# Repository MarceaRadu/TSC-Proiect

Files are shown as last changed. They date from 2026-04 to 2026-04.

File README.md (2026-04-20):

# InkTime - Proiect 

InkTime este un prototip de ceas inteligent construit în jurul platformei SoC nRF52840. Dispozitivul dispune de un display color TFT, conectivitate Bluetooth Low Energy (BLE 5.0), senzor pentru detecția mișcării și utilizează un sistem de alimentare liniar, conceput special pentru a fi eficient în utilizarea cotidiană.

## 2. Tabel Componente (Bill Of Materials)

| Componentă / Rol | Format (Package) | Cod JLCPCB | Fișă Tehnică (Datasheet) |
|---|---|---|---|
| **Microcontroler** (nRF52840-QIAA-R) | aQFN73 (7x7) | [C190794](https://jlcpcb.com/partdetail/Nordic_Semicon-NRF52840_QIAA_R/C190794) | [Datasheet](https://docs.nordicsemi.com/) |
| **Încărcător Baterie** (BQ25120YBGR) | DSBGA-9 | [C1682423](https://jlcpcb.com/partdetail/TexasInstruments-BQ25180YBGR/C3682423) | [Datasheet](https://www.ti.com/lit/ds/symlink/bq25180.pdf) |
| **Fuel Gauge** (MAX17048G+T10) | DFN-8 (2x2) | [C2682616](https://jlcpcb.com/partdetail/AnalogDevices-MAX17048G_T10/C2682616) | [Datasheet](https://www.analog.com/media/en/technical-documentation/data-sheets/MAX17048-MAX17049.pdf) |
| **Regulator Buck-Boost** (RT6160AWSC) | WLCSP-15 | [C7065276](https://jlcpcb.com/partdetail/Richtek_Tech-RT6160AWSC/C7065276) | [Datasheet](https://www.richtek.com/assets/product_file/RT6160A/DS6160A-05.pdf) |
| **Accelerometru** (BMA421) | LGA-12 (2x2) | [C5242966](https://jlcpcb.com/partdetail/Bosch_Sensortec-BMA421/C5242966) | [Datasheet](https://www.bosch-sensortec.com/media/boschsensortec/downloads/datasheets/bst-bma421-ds004.pdf) |
| **Driver Haptic** (DRV2605LDGSR) | VSSOP-10 | [C527464](https://jlcpcb.com/partdetail/TexasInstruments-DRV2605LDGSR/C527464) | [Datasheet](https://www.ti.com/lit/ds/symlink/drv2605l.pdf) |
| **Antenă BLE** (2450AT18B100E) | SMD 3216 | [C5179427](https://jlcpcb.com/partdetail/Johanson_Technology-2450AT18B100E/C5179427) | [Datasheet](https://www.johansontechnology.com/datasheets/2450AT18B100/2450AT18B100.pdf) |
| **Conector FPC** (Molex 503480-2400) | 24-pin 0.5mm FPC | [C2857168](https://jlcpcb.com/partdetail/Molex-5034802400/C2857160) | [Datasheet](https://www.molex.com/en-us/products/part-detail/5034802400) |
| **Butoane** (EVP-AKB31A) | SMD tactil | [C2845028](https://jlcpcb.com/partdetail/Panasonic-EVP_AKE31A/C2845028) | [Datasheet](https://industrial.panasonic.com/cdbs/www-data/pdf/ATV0000/ATV0000CE3.pdf) |
| **Mufă USB-C** (KH-TYPE-C-16P) | 16-pin SMD | [C2765186](https://jlcpcb.com/partdetail/Kinghelm-KH_TYPE_C_16P/C2765186) | [Datasheet](https://datasheet.lcsc.com/lcsc/2012121836_Kinghelm-KH-TYPE-C-16P_C2765186.pdf) |
| **Protecție ESD USB** (USBLC6-2SC6Y) | SOT-23-6 | [C7519](https://jlcpcb.com/partdetail/Stmicroelectronics-USBLC6_2SC6Y/C7519) | [Datasheet](https://www.st.com/resource/en/datasheet/usblc6-2.pdf) |
| **Tranzistor PFET** (Si2301CDS) | SOT-23 | [C10487](https://jlcpcb.com/partdetail/Changjiang_Electronics_Tech_CJ-SI2301CDS/C10487) | [Datasheet](https://www.vishay.com/docs/68749/si2301cds.pdf) |
| **Motor Vibrații** (LCM102733605F) | Fire atașate | [C7528006](https://jlcpcb.com/partdetail/7528806-LCM1027B3605F/C7528806) | [Datasheet](https://datasheet.lcsc.com/lcsc/2310131633_LCM-LCM1027B3605F_C7528806.pdf) |

**Componente Pasive & Periferice:**
* Interfață Programare: Header Tag-Connect 6-pin (TC2030-IDC)
* Cristale Oscilatoare: 32 MHz (2016) și 32.768 kHz (3215)
* Module externe: Display E-Paper / TFT 1.54 inch (FPC 24-pini), Acumulator LiPo 250 mAh
* Inductoare: 0.47uH (2012), 10uH (0402)
* Rezistențe (0201): 2x 10k, 2x 5.1k
* Condensatoare: 4x 12pF (0201), 5x 100nF (0201), 5x 4.7uF (0402), 2x 22uF (0402), 12x 1uF (0402)

## 3. Funcționalitatea Modulelor Hardware

**Unitatea de Procesare și Conectivitatea**
Creierul întregului sistem este cipul nRF52840 (la 64 MHz). Acesta execută logica aplicației și susține comunicarea wireless prin stiva BLE 5.0, permițând legătura cu smartphone-ul pentru sincronizarea timpului și preluarea notificărilor.

**Magistrale și Interfețe**
- **SPI (Doar transmisie):** Alocată exclusiv pentru display-ul TFT. Oferă o lățime de bandă mare, vitală pentru un framerate ridicat și tranziții fluide pe un ecran color.
- **I2C (400 kHz):** Prin intermediul acestei magistrale comunică senzorul inerțial (IMU) LSM6DS3TR-C. Folosirea I2C economisește pini valoroși și ușurează citirea datelor de accelerație.
- **PWM:** Comandă un tranzistor de tip N-MOSFET. Acesta joacă rolul de comutator de putere pentru motorul haptic (shaker-ul BST-BMV080), făcând posibilă generarea unor vibrații cu intensitate variabilă.

**Managementul Energiei (Power System)**
Pentru acest dispozitiv am implementat o arhitectură de alimentare liniară, punând accent pe fiabilitate și simplitate. Modulul BQ24040 primește 5V de la mufa USB-C și încarcă în condiții de siguranță bateria Li-Po de 250mAh (la un curent de 100mA). Mai departe, tensiunea variabilă a bateriei (3.0V - 4.2V) este coborâtă și stabilizată strict la 3.3V cu ajutorul unui regulator LDO (AP2112K). Acest LDO alimentează toată placa și a fost integrat datorită costului scăzut și a lipsei zgomotului electric la curenți mai mici de 600mA.

**Analiza Consumului de Energie**
Ecranele TFT, spre deosebire de cele e-paper, au nevoie de iluminare (backlight) continuă pentru a fi lizibile.
- *Consum în sarcină (Activ):* Aprox. 25 mA (TFT aprins la o luminozitate medie + procesorul activ).
- *Consum în repaus (Stand-by):* Aprox. 0.8 mA (Ecranul este oprit, MCU intră în modul sleep, funcția de BLE advertising este activă, iar IMU-ul așteaptă o mișcare pentru a trezi ceasul).
- *Estimare Autonomie:* Presupunând un scenariu zilnic cu 25 de treziri ale ecranului (a câte 5 secunde) și notificări haptice ocazionale, consumul se ponderează la o medie de 1.1 mA/h. În aceste condiții, acumulatorul de 250mAh asigură o durată de viață teoretică de 8 până la 9 zile de funcționare continuă.

## 4. Maparea Pinilor pentru nRF52840

Pinii au fost distribuiți având ca scop principal optimizarea traseelor de cupru pe placă (routing) și izolarea semnalelor rapide.

| Pin nRF | Periferic | Justificare / Rol Tehnic |
|---|---|---|
| **P0.29** | TFT SCK | Semnal de ceas rapid. Rutat special pe marginea PCB-ului către pamblica ecranului. |
| **P0.31** | TFT MOSI | Pin de date SPI. Tratat în paralel cu SCK pentru a evita degradarea semnalului grafic. |
| **P0.02** | TFT CS | Chip Select (activează display-ul pe magistrală). |
| **P0.26** | TFT DC | Data/Command. Necesar în mod obligatoriu pentru interpretarea comenzilor de către driverul ST7789. |
| **P0.27** | I2C SCL | Semnalul de clock pentru I2C, utilizat exclusiv de IMU. |
| **P0.28** | I2C SDA | Date I2C. Grupate special la distanță de liniile SPI pentru a elimina posibilele interferențe (crosstalk). |
| **P1.11** | Shaker PWM | Portul 1 a fost alocat pentru comenzi mecanice și de forță. Controlează grila tranzistorului de pe motoraș. |
| **P1.04** | Buton 1 (Sus) | GPIO setat ca intrare cu rezistență de pull-up internă. Folosit și pentru a trezi sistemul din hibernare. |
| **P1.05** | Buton 2 (OK) | Intrare digitală. Toți pinii butoanelor sunt adiacenți pentru a face rutarea pe margine extrem de scurtă. |
| **P1.06** | Buton 3 (Jos) | Intrare digitală pentru navigarea interfeței grafice. |
| **VBUS** | 5V USB | Pin hardware nativ al procesorului, capabil să citească prezența curentului de la încărcător. |
| **SWDIO** | Programare | Pin de date folosit la prima "flash-uire" a codului prin SWD / J-Link. |
| **SWDCLK**| Programare | Semnalul de ceas pentru protocolul de depanare SWD. |

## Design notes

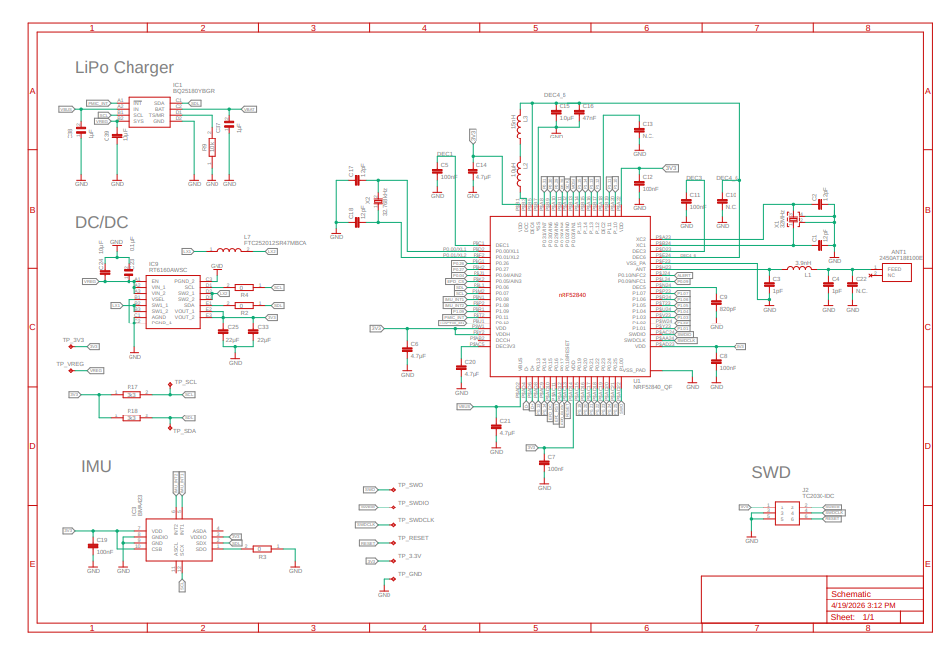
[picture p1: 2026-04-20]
Images/schematic2.png

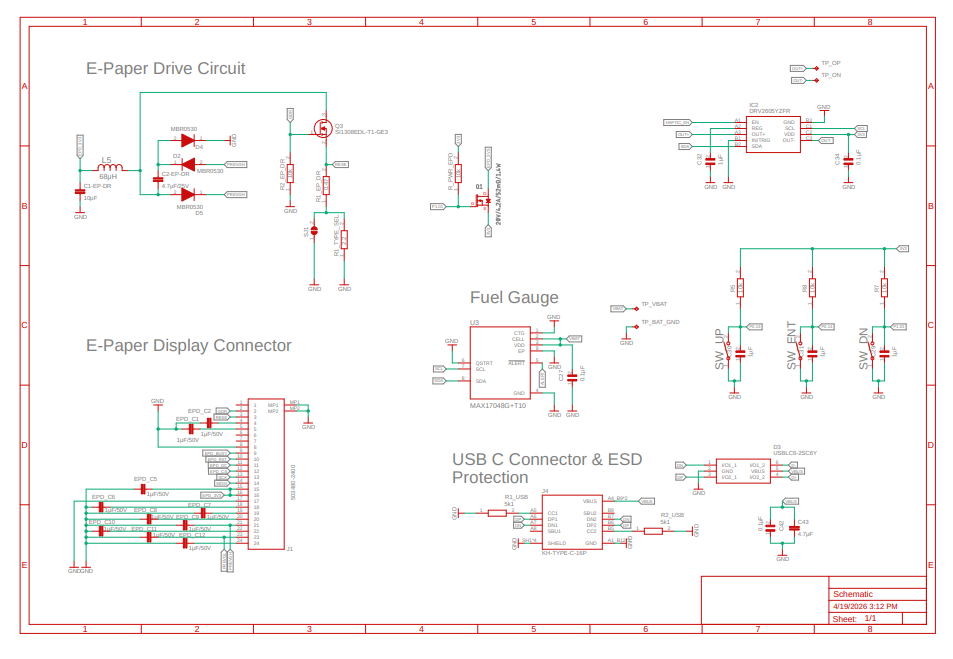
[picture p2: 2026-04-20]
Images/schematic1.png

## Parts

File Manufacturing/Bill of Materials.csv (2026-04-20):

Qty | Value | Device | Package | Parts | Description | ARROW_PART_NUMBER | ARROW_PRICE-STOCK | AVAILABILITY | CHECK_PRICES | COPYRIGHT | DESCRIPTION | DIGI-KEY_PART_NUMBER_1 | DIGI-KEY_PART_NUMBER_2 | DIGI-KEY_PART_NUMBER_3 | HEIGHT | JLCPCB | MANUFACTURER_NAME | MANUFACTURER_PART_NUMBER | MF | MFR_NAME | MOUSER_PART_NUMBER | MOUSER_PRICE-STOCK | MP | PACKAGE | POPULARITY | PRICE | PROD_ID | PURCHASE-URL | SNAPEDA_LINK | SPICEMODEL | SPICEPREFIX | TP_SIGNAL_NAME | VALUE
1 |  | ESP32_C6_LIBRARY_7_JUMPER_SJ | ESP32_C6_LIBRARY_7_JUMPER_SJ | SJ1 | SMD solder JUMPER |  |  |  |  |  |  |  |  |  |  |  |  |  |  |  |  |  |  |  | 3
3 | 0 | ERA-1AEB3401C_CPF0201D7K68C1 | ERA-1AEB3401C_0201 | R2, R3, R4 | 7.68k 0201 Thin Film Surface Mount Fixed Resistor +/-0.5% 0.031W CPF0201D7K68C1
4 | 0.1µF | GRM011R60J152KE01L_2_GRM011R60J152KE01L | GRM011R60J152KE01L_2_CAPC0201X13N | C23, C27, C34, C42 | Check availability |  |  | In Stock | https://www.snapeda.com/parts/GRM011R60J152KE01L/Murata/view-part/?ref=eda |  | SMD Capacitor X5R(EIA) with Capacitance: 1500pF Tol. 10%. Rated Voltage: 6.3Vdc |  |  |  |  |  |  |  | Murata |  |  |  | GRM011R60J152KE01L | 0201 Murata |  | None |  |  | https://www.snapeda.com/parts/GRM011R60J152KE01L/Murata/view-part/?ref=snap
1 | 0.47 | ERA-1AEB3401C_CPF0201D7K68C1 | ERA-1AEB3401C_0201 | R1_EP_DR | 7.68k 0201 Thin Film Surface Mount Fixed Resistor +/-0.5% 0.031W CPF0201D7K68C1
1 | 1.0µF | ESP32_C6_LIBRARY_1_ESP32_WROVER_EAGLE-LTSPICE_CC0402 | ESP32_C6_LIBRARY_1_ESP32_WROVER_EAGLE-LTSPICE_C0402 | C15 | CAPACITOR, European symbol |  |  |  |  |  |  |  |  |  |  |  |  |  |  |  |  |  |  |  |  |  |  |  |  | NONE | C
6 | 100nF | NORDIC_NRF_3_CAPACITOR_0201_L | NORDIC_NRF_3_RESC0201_L | C5, C7, C8, C11, C12, C19 | Generic chip capacitor
6 | 10k | ERA-1AEB3401C_CPF0201D7K68C1 | ERA-1AEB3401C_0201 | R2_EP_DR, R5, R7, R8, R9, R_PWR_EPD | 7.68k 0201 Thin Film Surface Mount Fixed Resistor +/-0.5% 0.031W CPF0201D7K68C1
3 | 10µF | ESP32_C6_LIBRARY_1_ESP32_WROVER_EAGLE-LTSPICE_CC0402 | ESP32_C6_LIBRARY_1_ESP32_WROVER_EAGLE-LTSPICE_C0402 | C1-EP-DR, C24, C39 | CAPACITOR, European symbol |  |  |  |  |  |  |  |  |  |  |  |  |  |  |  |  |  |  |  |  |  |  |  |  | NONE | C
1 | 10µH | NORDIC_NRF_2_INDUCTOR_0201_L | NORDIC_NRF_2_RESC0402_L | L2 | Generic chip inductor
4 | 12pF | NORDIC_NRF_3_CAPACITOR_0201_L | NORDIC_NRF_3_RESC0201_L | C1, C2, C17, C18 | Generic chip capacitor
1 | 15nH | NORDIC_NRF_2_INDUCTOR_0402_L | NORDIC_NRF_2_RESC0402_L | L3 | Generic chip inductor
2 | 1pF | NORDIC_NRF_3_CAPACITOR_0201_L | NORDIC_NRF_3_RESC0201_L | C3, C4 | Generic chip capacitor
6 | 1µF | GRM011R60J152KE01L_2_GRM011R60J152KE01L | GRM011R60J152KE01L_2_CAPC0201X13N | C29, C30, C31, C32, C37, C38 | Check availability |  |  | In Stock | https://www.snapeda.com/parts/GRM011R60J152KE01L/Murata/view-part/?ref=eda |  | SMD Capacitor X5R(EIA) with Capacitance: 1500pF Tol. 10%. Rated Voltage: 6.3Vdc |  |  |  |  |  |  |  | Murata |  |  |  | GRM011R60J152KE01L | 0201 Murata |  | None |  |  | https://www.snapeda.com/parts/GRM011R60J152KE01L/Murata/view-part/?ref=snap
10 | 1µF/50V | PERFECT_0402_CAP_0402 | PERFECT_0402_0402 | EPD_C1, EPD_C2, EPD_C5, EPD_C6, EPD_C7, EPD_C8, EPD_C9, EPD_C10, EPD_C11, EPD_C12 | 0402 (1005 Metric)
1 | 2.2 | ERA-1AEB3401C_CPF0201D7K68C1 | ERA-1AEB3401C_0201 | R1_TYPE_SEL | 7.68k 0201 Thin Film Surface Mount Fixed Resistor +/-0.5% 0.031W CPF0201D7K68C1
3 | 2025-10-22_07-23-44_LIBRARY_EVP-AKE31ASW_EVP-AKE31A_PAN | 2025-10-22_07-23-44_LIBRARY_EVP-AKE31ASW_EVP-AKE31A_PAN | 2025-10-22_07-23-44_LIBRARY_SW_EVP-AKE31A_PAN | SW_DN, SW_ENT, SW_UP |  |  |  |  |  | Copyright (C) 2025 Ultra Librarian. All rights reserved. |  | P123437TR-ND | P123437CT-ND | P123437DKR-ND |  |  | Panasonic | EVP-AKE31A
1 | 20V/4.2A/52mO/1.4W | ESP32_C6_LIBRARY_4_ESP32_WROVER_SPARKFUN-DISCRETESEMI_MOSFET_PCH-DMG2305UX-7 | ESP32_C6_LIBRARY_4_ESP32_C6_LIBRARY_4_ESP32_C6_LIBRARY_4_ESP32_C6_LIBRARY_4_ESP32_WROVER_SPARKFUN-DISCRETESEMI_SOT23-3 | Q1 | P-channel MOSFETs |  |  |  |  |  |  |  |  |  |  |  |  |  |  |  |  |  |  |  |  |  | TRAN-14388 |  |  |  |  |  | 20V/4.2A/52mO/1.4W
2 | 22µF | ESP32_C6_LIBRARY_1_ESP32_WROVER_EAGLE-LTSPICE_CC0402 | ESP32_C6_LIBRARY_1_ESP32_WROVER_EAGLE-LTSPICE_C0402 | C25, C33 | CAPACITOR, European symbol |  |  |  |  |  |  |  |  |  |  |  |  |  |  |  |  |  |  |  |  |  |  |  |  | NONE | C
1 | 2450AT18B100E | 2450AT18B100E_2450AT18B100E | 2450AT18B100E_ANTC3216X140N | ANT1 | Antennas 2.45GHz ANTENNA | 2450AT18B100E | https://www.arrow.com/en/products/2450at18b100e/johanson-dielectrics?utm_currency=USD&region=nac |  |  |  | Antennas 2.45GHz ANTENNA |  |  |  | 1.4mm |  | JOHANSON TECHNOLOGY | 2450AT18B100E |  |  | 609-2450AT18B100E | https://www.mouser.co.uk/ProductDetail/Johanson-Technology/2450AT18B100E?qs=yCnrNFeXz%252Bh5MFsFIXGZGA%3D%3D
1 | 3.9nH | NORDIC_NRF_2_INDUCTOR_0402_L | NORDIC_NRF_2_RESC0402_L | L1 | Generic chip inductor
1 | 32.768kHz | NORDIC_NRF_1_XTAL_32KHZ | NORDIC_NRF_1_XTAL_3215_N | X2
1 | 32MHz | NORDIC_NRF_XTAL_32MHZ | NORDIC_NRF_BT-XTAL_2016_N | X1
2 | 3k3 | ERA-1AEB3401C_CPF0201D7K68C1 | ERA-1AEB3401C_0201 | R17, R18 | 7.68k 0201 Thin Film Surface Mount Fixed Resistor +/-0.5% 0.031W CPF0201D7K68C1
4 | 4.7µF | ESP32_C6_LIBRARY_1_ESP32_WROVER_EAGLE-LTSPICE_CC0402 | ESP32_C6_LIBRARY_1_ESP32_WROVER_EAGLE-LTSPICE_C0402 | C6, C14, C20, C21 | CAPACITOR, European symbol |  |  |  |  |  |  |  |  |  |  |  |  |  |  |  |  |  |  |  |  |  |  |  |  | NONE | C
1 | 4.7µF | PERFECT_0402_CAP_0402 | PERFECT_0402_0402 | C43 | 0402 (1005 Metric)
1 | 4.7µF/25V | ESP32_C6_LIBRARY_1_ESP32_WROVER_EAGLE-LTSPICE_CC0402 | ESP32_C6_LIBRARY_1_ESP32_WROVER_EAGLE-LTSPICE_C0402 | C2-EP-DR | CAPACITOR, European symbol |  |  |  |  |  |  |  |  |  |  |  |  |  |  |  |  |  |  |  |  |  |  |  |  | NONE | C
1 | 47nF | NORDIC_NRF_3_CAPACITOR_0201_L | NORDIC_NRF_3_RESC0201_L | C16 | Generic chip capacitor
1 | 503480-2400 | 503480-2400_503480-2400 | 503480-2400_5034802400 | J1 | FFC & FPC Connectors 0.5mm FPC RA SMT Dual Contact 24Ckt |  |  |  |  |  | FFC & FPC Connectors 0.5mm FPC RA SMT Dual Contact 24Ckt |  |  |  | 1.87mm |  | Molex | 503480-2400 |  |  | 538-503480-2400 | https://www.mouser.co.uk/ProductDetail/Molex/503480-2400?qs=OAhjpuo3Vu7efIoxFh9AOw%3D%3D
2 | 5k1 | ERA-1AEB3401C_CPF0201D7K68C1 | ERA-1AEB3401C_0201 | R1_USB, R2_USB | 7.68k 0201 Thin Film Surface Mount Fixed Resistor +/-0.5% 0.031W CPF0201D7K68C1
1 | 68µH | ESP32_C6_LIBRARY_2_744043680IND_4828-WE-TPC_WRE | ESP32_C6_LIBRARY_2_IND_4828-WE-TPC_WRE | L5 |  |  |  |  |  | Copyright (C) 2024 Ultra Librarian. All rights reserved. |  |  |  |  |  |  |  | 744043680 |  | Wurth Electronics
1 | 820pF | NORDIC_NRF_3_CAPACITOR_0201_L | NORDIC_NRF_3_RESC0201_L | C9 | Generic chip capacitor
1 | BMA423 | BMA423_BMA423 | BMA423_BMA423 | IC3 | Accelerometers Triaxial low-g 12bit Acceleration Sensor | BMA423 | https://www.arrow.com/en/products/bma423/bosch |  |  |  | Accelerometers Triaxial low-g 12bit Acceleration Sensor |  |  |  | 1mm |  | BOSCH | BMA423 |  |  | 262-BMA423 | https://www.mouser.co.uk/ProductDetail/Bosch-Sensortec/BMA423?qs=HXFqYaX1Q2xC%252BSgeGoX3mg%3D%3D
1 | BQ25180YBGR | BQ25180YBGR_BQ25180YBGR | BQ25180YBGR_BGA8C40P2X4_100X155X50 | IC1 | Charger IC Lithium Ion/Polymer, Lithium Iron Phosphate 8-DSBGA (1.6x1.1) | BQ25180YBGR | https://www.arrow.com/en/products/bq25180ybgr/texas-instruments?utm_currency=USD&region=nac |  |  |  | Charger IC Lithium Ion/Polymer | Lithium Iron Phosphate 8-DSBGA (1.6x1.1) |  |  |  | 0.5mm |  | Texas Instruments | BQ25180YBGR |  |  | 595-BQ25180YBGR | https://www.mouser.co.uk/ProductDetail/Texas-Instruments/BQ25180YBGR?qs=doiCPypUmgEWjAK%252BJAX6Tw%3D%3D
1 | DRV2605YZFR | DRV2605YZFR_DRV2605YZFR | DRV2605YZFR_BGA9C50P3X3_144X144X62 | IC2 | Haptic Driver for ERM/LRA with Built-In Library and Smart Loop Architecture | DRV2605YZFR | https://www.arrow.com/en/products/drv2605yzfr/texas-instruments?region=nac |  |  |  | Haptic Driver for ERM/LRA with Built-In Library and Smart Loop Architecture |  |  |  | 0.625mm |  | Texas Instruments | DRV2605YZFR
1 | FTC252012SR47MBCA | MLP2016SR47MT0S1_FTC252012SR47MBCA | MLP2016SR47MT0S1_INDC2016X100N | L7 | SMD / SMT Inductors (Coils), L=0.47?H, L x W x T : |  |  |  |  |  | SMD / SMT Inductors (Coils) | L=0.47?H | L x W x T : |  |  |  | 1mm | https://jlcpcb.com/partdetail/6763488-FTC252012SR47MBCA/C5832368 | TDK | FTC252012SR47MBCA
14 | HECTOR_WATCH_1_TPTP20R | HECTOR_WATCH_1_TPTP20R | HECTOR_WATCH_1_TP20R | TP_3.3V, TP_3V3, TP_BAT_GND, TP_GND, TP_ON, TP_OP, TP_RESET, TP_SCL, TP_SDA, TP_SWDCLK, TP_SWDIO, TP_SWO, TP_VBAT, TP_VREG | Test pad |  |  |  |  |  |  |  |  |  |  |  |  |  |  |  |  |  |  |  | 2
1 | KH-TYPE-C-16P | KH-TYPE-C-16P_KH-TYPE-C-16P | KH-TYPE-C-16P_KINGHELM_KH-TYPE-C-16P | J4 | Check availability |  |  | Not in stock | https://www.snapeda.com/parts/KH-TYPE-C-16P/Kinghelm/view-part/?ref=eda |  |  |  |  |  |  |  |  |  | kinghelm |  |  |  | KH-TYPE-C-16P | None |  | None |  |  | https://www.snapeda.com/parts/KH-TYPE-C-16P/Kinghelm/view-part/?ref=snap
1 | MAX17048G+T10 | ESP32_C6_LIBRARY_MAX17048G+T10 | ESP32_C6_LIBRARY_SON50P200X200X80-9N | U3 | Check availability |  |  | In Stock | https://www.snapeda.com/parts/MAX17048G+T10/Analog+Devices/view-part/?ref=eda |  | 3µA 1-Cell/2-Cell Fuel Gauge with ModelGauge |  |  |  |  |  |  |  | Analog Devices |  |  |  | MAX17048G+T10 | TDFN-8 Maxim |  | None |  | https://www.snapeda.com/api/url_track_click_mouser/?unipart_id=329239&manufacturer=Analog Devices&part_name=MAX17048G+T10&search_term=None | https://www.snapeda.com/parts/MAX17048G+T10/Analog+Devices/view-part/?ref=snap
3 | MBR0530 | ESP32_C6_LIBRARY_5_MBR0530 | ESP32_C6_LIBRARY_5_SOD3716X135N | D2, D4, D5 | ON SEMICONDUCTOR - MBR0530 - DIODE, SCHOTTKY, 0.5A, 30V, SOD-123 |  |  | In Stock | https://www.snapeda.com/parts/MBR0530/Onsemi/view-part/?ref=eda |  | Diode Schottky 30 V 500mA Surface Mount SOD-123 |  |  |  |  |  |  |  | ON Semiconductor |  |  |  | MBR0530 | SOD-123-2 ON Semiconductor |  | None |  | https://www.snapeda.com/api/url_track_click_mouser/?unipart_id=179458&manufacturer=ON Semiconductor&part_name=MBR0530&search_term=None | https://www.snapeda.com/parts/MBR0530/Onsemi/view-part/?ref=snap
3 | N.C. | NORDIC_NRF_3_CAPACITOR_0201_L | NORDIC_NRF_3_RESC0201_L | C10, C13, C22 | Generic chip capacitor
1 | NRF52840_QF | NORDIC_NRF_4_NRF52840_QF | NORDIC_NRF_4_AQFN50P700X700X85_HS-74N | U1 | nRF52840
1 | RT6160AWSC | RT6160AWSC_RT6160AWSC | RT6160AWSC_BGA15C40P3X5_140X230X60 | IC9 | Buck-Boost Regulator Positive Output Step-Up/Step-Down I2C DC-DC Controller IC 15-WL-CSP (BSC) (1.4x2.3) |  |  |  |  |  | Buck-Boost Regulator Positive Output Step-Up/Step-Down I2C DC-DC Controller IC 15-WL-CSP (BSC) (1.4x2.3) |  |  |  | 0.6mm |  | RICHTEK | RT6160AWSC |  |  | 835-RT6160AWSC | https://www.mouser.co.uk/ProductDetail/Richtek/RT6160AWSC?qs=amGC7iS6iy%2FLd9PSoixZXQ%3D%3D
1 | SI1308EDL-T1-GE3 | ESP32_C6_LIBRARY_6_SI1308EDL-T1-GE3 | ESP32_C6_LIBRARY_4_ESP32_C6_LIBRARY_4_ESP32_C6_LIBRARY_4_ESP32_C6_LIBRARY_4_ESP32_WROVER_SPARKFUN-DISCRETESEMI_SOT23-3 | Q3 | MOSFET N-Ch 30V 1.5A TrenchFET SC70 Vishay Si1308EDL-T1-GE3 N-channel MOSFET Transistor, 1.5 A, 30 V, 3-Pin SC-70 |  |  | In Stock | https://www.snapeda.com/parts/SI1308EDL-T1-GE3/Vishay+Siliconix/view-part/?ref=eda |  | Si1308EDL-T1-GE3 N-channel MOSFET Transistor | 1.5 A | 30 V | 3-Pin SC-70 | Siliconix / Vishay SI1308EDL-T1-GE3 |  |  |  |  |  |  |  | Vishay Siliconix |  |  |  | SI1308EDL-T1-GE3 | SOT-323 Vishay Semiconductor |  | None |  | https://www.snapeda.com/api/url_track_click_mouser/?unipart_id=274603&manufacturer=Vishay Siliconix&part_name=SI1308EDL-T1-GE3&search_term=None | https://www.snapeda.com/parts/SI1308EDL-T1-GE3/Vishay+Siliconix/view-part/?ref=snap
1 | TC2030-IDC | TC2030-IDC_TC2030-IDC | TC2030-IDC_TC2030IDC | J2 | CABLE ADAPTER 6 POS |  |  |  |  |  | CABLE ADAPTER 6 POS |  |  |  | 19mm |  | Tag Connect | TC2030-IDC
1 | USBLC6-2SC6Y | ESP32_C6_LIBRARY_3_USBLC6-2SC6Y | ESP32_C6_LIBRARY_3_SOT95P280X145-6N | D3 | Low Cap. ESD Protection Auto SOT-23-6 STMicroelectronics USBLC6-2SC6Y, Dual Uni-Directional TVS Diode Array, 6-Pin SOT-23 |  |  | In Stock | https://www.snapeda.com/parts/USBLC6-2SC6Y/STMicroelectronics/view-part/?ref=eda |  | 17V Clamp 5A (8/20µs) Ipp Tvs Diode Surface Mount SOT-23-6 |  |  |  |  |  |  |  | STMicroelectronics |  |  |  | USBLC6-2SC6Y | SOT-23-6 STMicroelectronics |  | None |  |  | https://www.snapeda.com/parts/USBLC6-2SC6Y/STMicroelectronics/view-part/?ref=snap

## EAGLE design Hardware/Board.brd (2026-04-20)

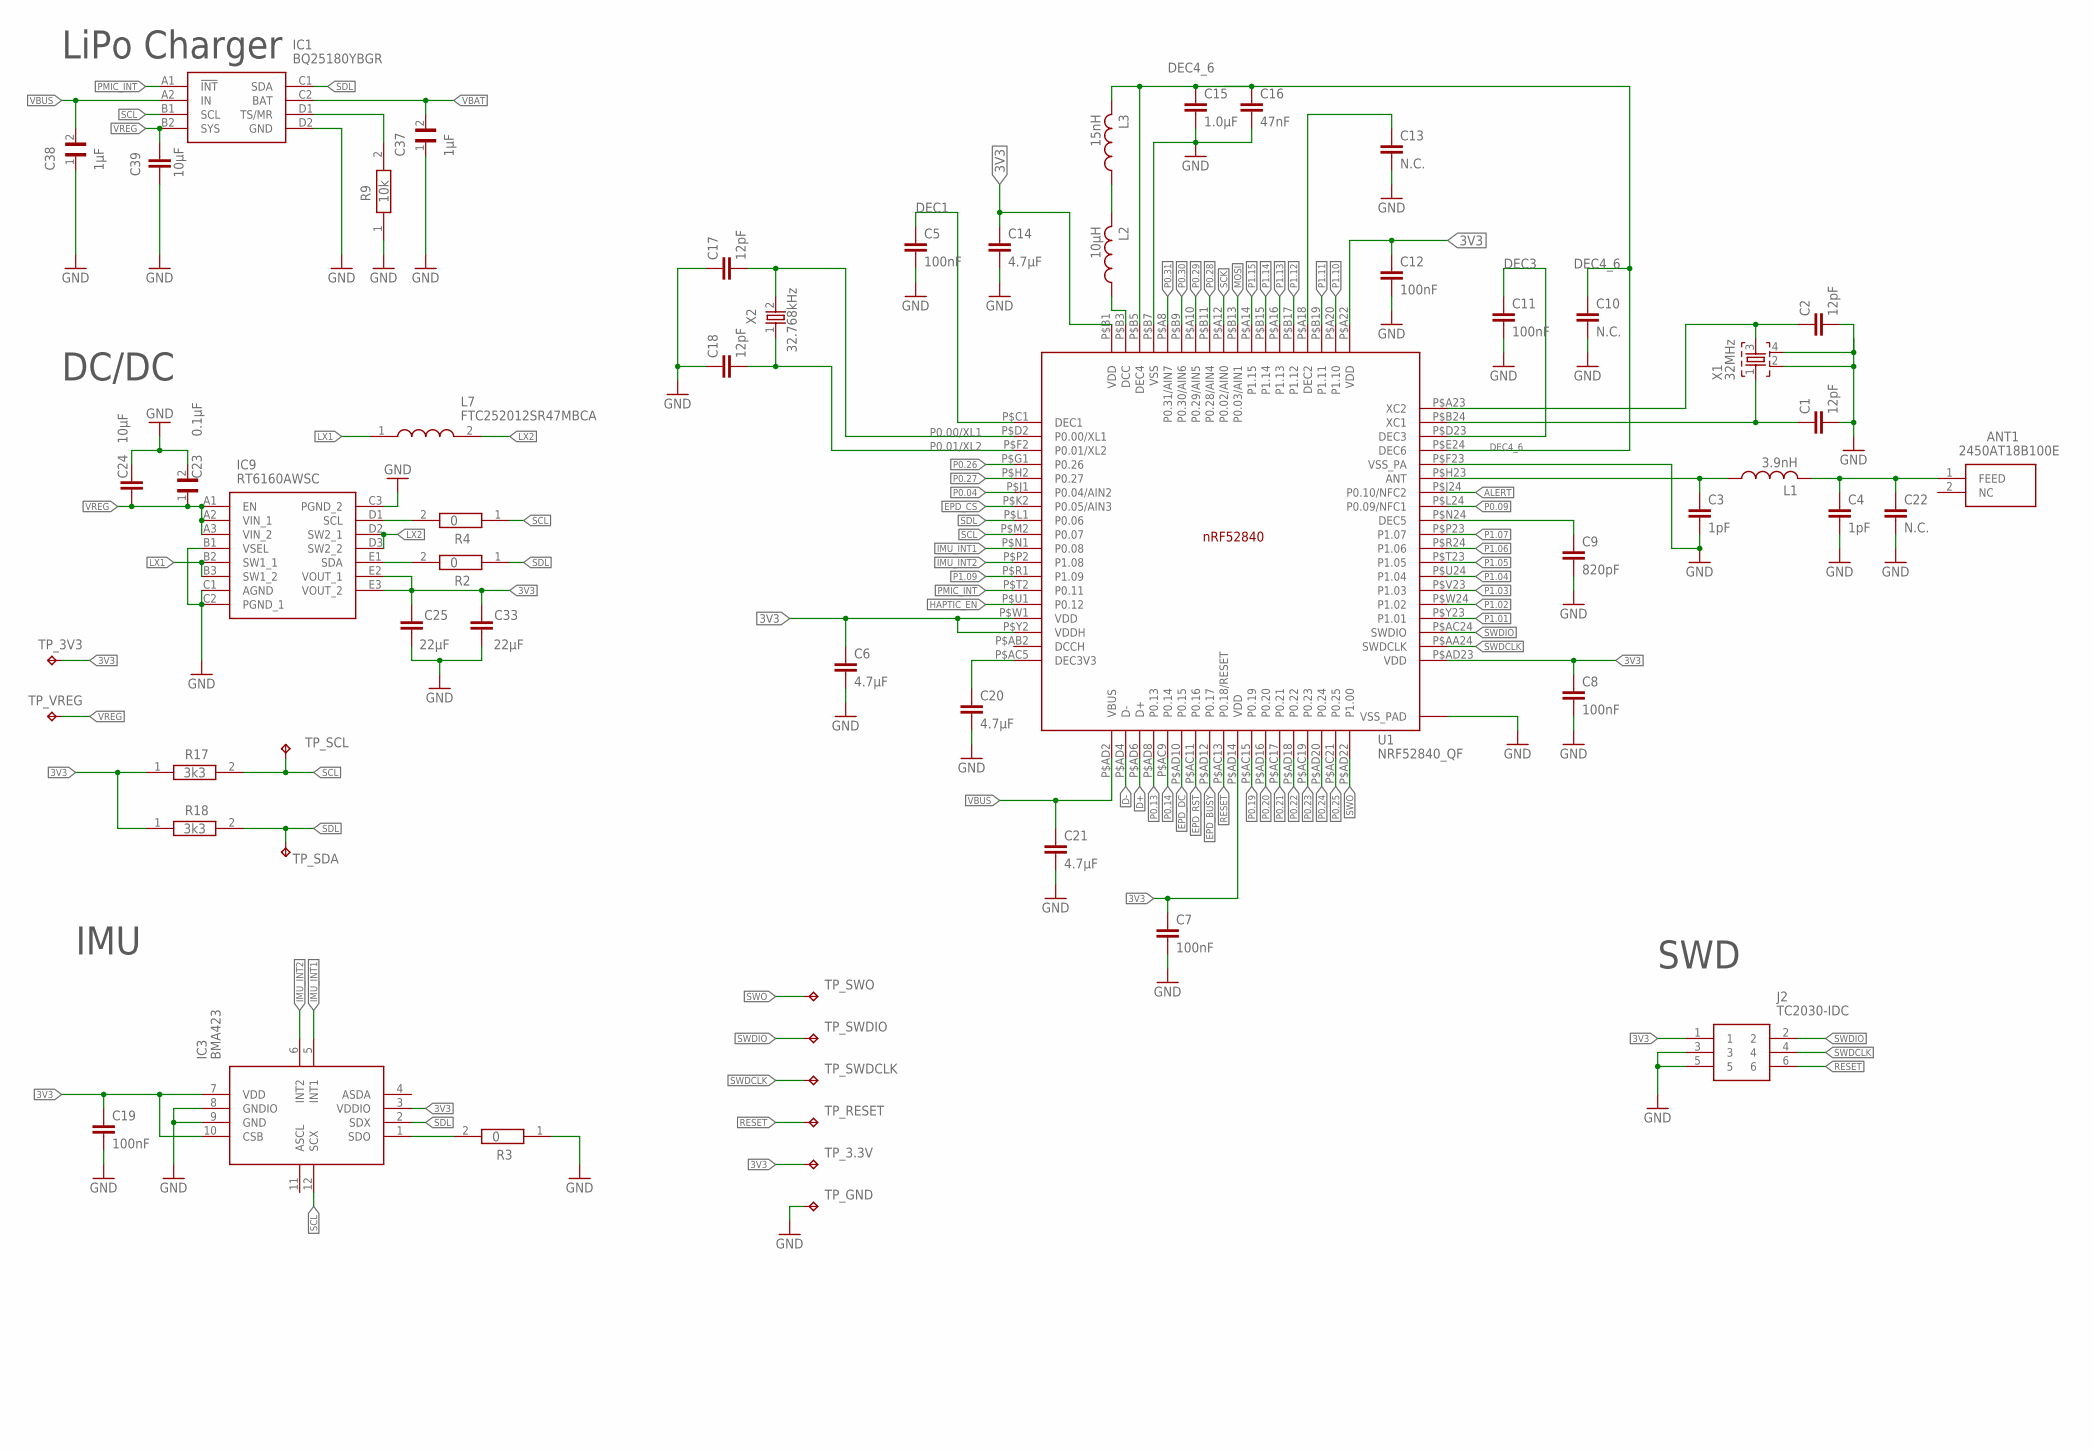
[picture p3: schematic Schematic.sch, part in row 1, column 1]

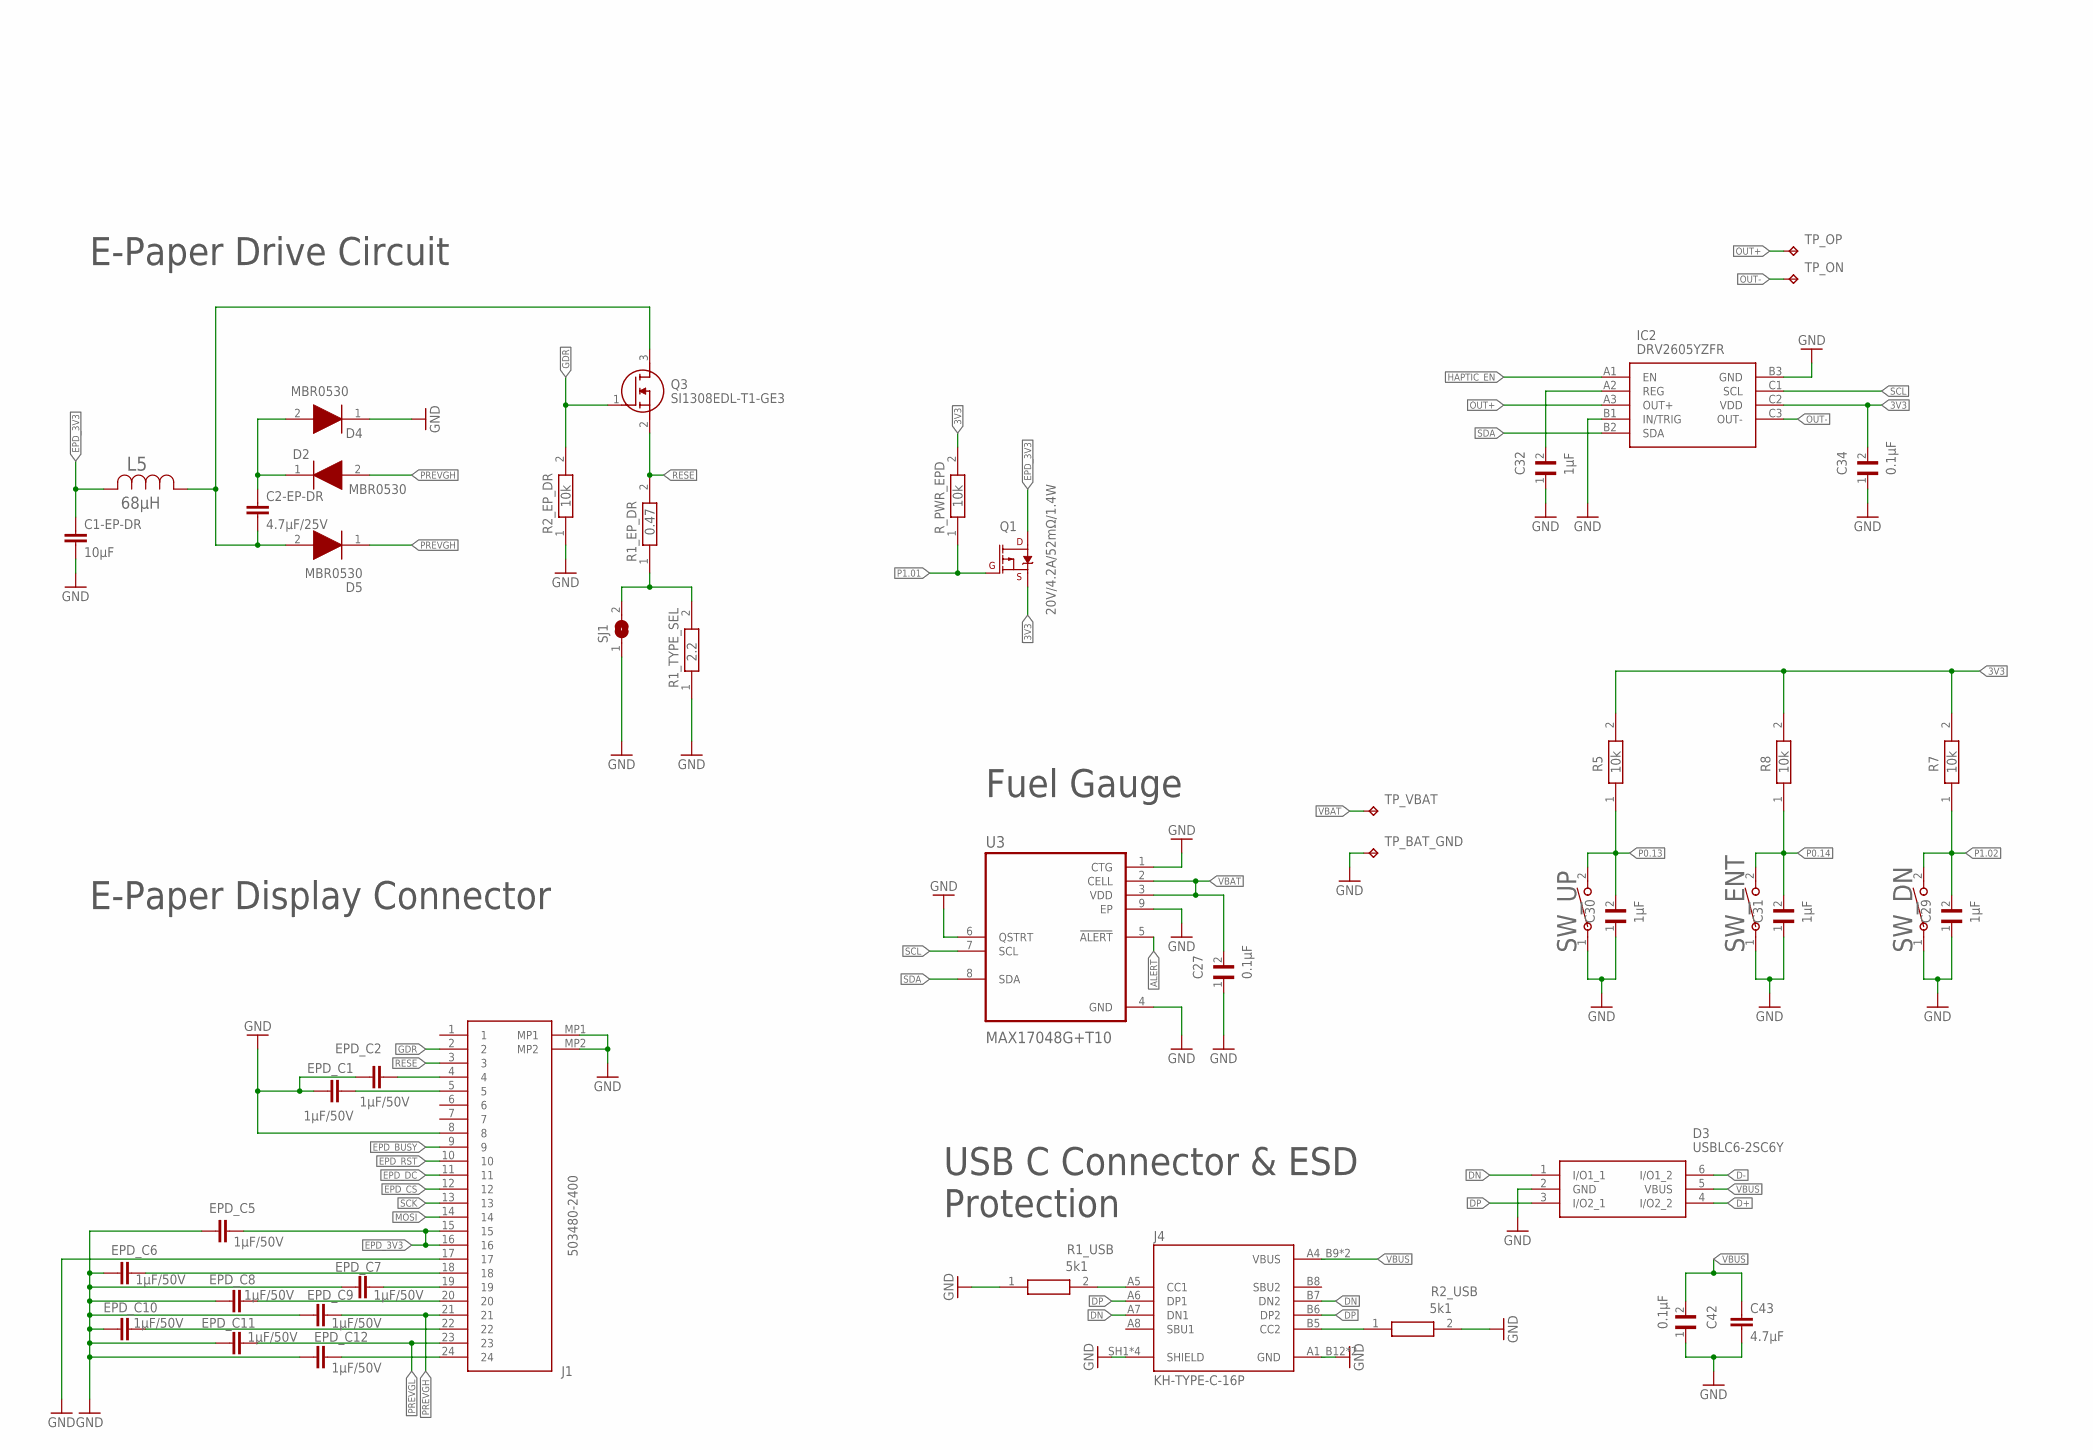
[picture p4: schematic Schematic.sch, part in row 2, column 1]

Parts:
ANT1: 2450AT18B100E; 2450AT18B100E_ANTC3216X140N
C1, C2, C17, C18: 12pF; NORDIC_NRF_3_RESC0201_L
C1-EP-DR, C24, C39: 10μF; ESP32_C6_LIBRARY_1_ESP32_WROVER_EAGLE-LTSPICE_C0402
C2-EP-DR: 4.7μF/25V; ESP32_C6_LIBRARY_1_ESP32_WROVER_EAGLE-LTSPICE_C0402
C3, C4: 1pF; NORDIC_NRF_3_RESC0201_L
C5, C7, C8, C11, C12, C19: 100nF; NORDIC_NRF_3_RESC0201_L
C6, C14, C20, C21: 4.7μF; ESP32_C6_LIBRARY_1_ESP32_WROVER_EAGLE-LTSPICE_C0402
C9: 820pF; NORDIC_NRF_3_RESC0201_L
C10, C13, C22: N.C.; NORDIC_NRF_3_RESC0201_L
C15: 1.0μF; ESP32_C6_LIBRARY_1_ESP32_WROVER_EAGLE-LTSPICE_C0402
C16: 47nF; NORDIC_NRF_3_RESC0201_L
C23, C27, C34, C42: 0.1μF; GRM011R60J152KE01L_2_CAPC0201X13N
C25, C33: 22μF; ESP32_C6_LIBRARY_1_ESP32_WROVER_EAGLE-LTSPICE_C0402
C29, C30, C31, C32, C37, C38: 1μF; GRM011R60J152KE01L_2_CAPC0201X13N
C43: 4.7μF; PERFECT_0402_0402
D2, D4, D5: MBR0530; ESP32_C6_LIBRARY_5_SOD3716X135N
D3: USBLC6-2SC6Y; ESP32_C6_LIBRARY_3_SOT95P280X145-6N
EPD_C1, EPD_C2, EPD_C5, EPD_C6, EPD_C7, EPD_C8, EPD_C9, EPD_C10, EPD_C11, EPD_C12: 1μF/50V; PERFECT_0402_0402
IC1: BQ25180YBGR; BQ25180YBGR_BGA8C40P2X4_100X155X50
IC2: DRV2605YZFR; DRV2605YZFR_BGA9C50P3X3_144X144X62
IC3: BMA423; BMA423_BMA423
IC9: RT6160AWSC; RT6160AWSC_BGA15C40P3X5_140X230X60
J1: 503480-2400; 503480-2400_5034802400
J2: TC2030-IDC; TC2030-IDC_TC2030IDC
J4: KH-TYPE-C-16P; KH-TYPE-C-16P_KINGHELM_KH-TYPE-C-16P
L1: 3.9nH; NORDIC_NRF_2_RESC0402_L
L2: 10μH; NORDIC_NRF_2_RESC0402_L
L3: 15nH; NORDIC_NRF_2_RESC0402_L
L5: 68μH; ESP32_C6_LIBRARY_2_IND_4828-WE-TPC_WRE
L7: FTC252012SR47MBCA; MLP2016SR47MT0S1_INDC2016X100N
Q1: 20V/4.2A/52mΩ/1.4W; ESP32_C6_LIBRARY_4_ESP32_C6_LIBRARY_4_ESP32_C6_LIBRARY_4_ES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
Q3: SI1308EDL-T1-GE3; ESP32_C6_LIBRARY_4_ESP32_C6_LIBRARY_4_ESP32_C6_LIBRARY_4_ES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
R1_EP_DR: 0.47; ERA-1AEB3401C_0201
R1_TYPE_SEL: 2.2; ERA-1AEB3401C_0201
R1_USB, R2_USB: 5k1; ERA-1AEB3401C_0201
R2, R3, R4: 0; ERA-1AEB3401C_0201
R2_EP_DR, R5, R7, R8, R9: 10k; ERA-1AEB3401C_0201
R17, R18: 3k3; ERA-1AEB3401C_0201
R_PWR_EPD: 10k; ERA-1AEB3401C_0201
SJ1: ESP32_C6_LIBRARY_7_JUMPER_SJ
SW_DN: 2025-10-22_07-23-44_LIBRARY_EVP-AKE31ASW_EVP-AKE3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; 2025-10-22_07-23-44_LIBRARY_SW_EVP-AKE31A_PAN
SW_ENT: 2025-10-22_07-23-44_LIBRARY_EVP-AKE31ASW_EVP-AKE3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; 2025-10-22_07-23-44_LIBRARY_SW_EVP-AKE31A_PAN
SW_UP: 2025-10-22_07-23-44_LIBRARY_EVP-AKE31ASW_EVP-AKE3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; 2025-10-22_07-23-44_LIBRARY_SW_EVP-AKE31A_PAN
TP_3.3V, TP_3V3: HECTOR_WATCH_1_TPTP20R; HECTOR_WATCH_1_TP20R
TP_BAT_GND: HECTOR_WATCH_1_TPTP20R; HECTOR_WATCH_1_TP20R
TP_GND: HECTOR_WATCH_1_TPTP20R; HECTOR_WATCH_1_TP20R
TP_ON: HECTOR_WATCH_1_TPTP20R; HECTOR_WATCH_1_TP20R
TP_OP: HECTOR_WATCH_1_TPTP20R; HECTOR_WATCH_1_TP20R
TP_RESET: HECTOR_WATCH_1_TPTP20R; HECTOR_WATCH_1_TP20R
TP_SCL: HECTOR_WATCH_1_TPTP20R; HECTOR_WATCH_1_TP20R
TP_SDA: HECTOR_WATCH_1_TPTP20R; HECTOR_WATCH_1_TP20R
TP_SWDCLK: HECTOR_WATCH_1_TPTP20R; HECTOR_WATCH_1_TP20R
TP_SWDIO: HECTOR_WATCH_1_TPTP20R; HECTOR_WATCH_1_TP20R
TP_SWO: HECTOR_WATCH_1_TPTP20R; HECTOR_WATCH_1_TP20R
TP_VBAT: HECTOR_WATCH_1_TPTP20R; HECTOR_WATCH_1_TP20R
TP_VREG: HECTOR_WATCH_1_TPTP20R; HECTOR_WATCH_1_TP20R
U1: NRF52840_QF; NORDIC_NRF_4_AQFN50P700X700X85_HS-74N
U3: MAX17048G+T10; ESP32_C6_LIBRARY_SON50P200X200X80-9N
X1: 32MHz; NORDIC_NRF_BT-XTAL_2016_N
X2: 32.768kHz; NORDIC_NRF_1_XTAL_3215_N

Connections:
3V3: C6.1, C7.1, C8.1, C12.1, C14.1, C19.1, C33.1, C34.2, IC2.C2 (VDD), IC3.3 (VDDIO), IC3.7 (VDD), IC3.10 (CSB), IC9.E3 (VOUT_2), J2.1, Q1.2 (S), R5.2, R7.2, R8.2, R17.1, R18.1, R_PWR_EPD.2, TP_3.3V.TP, TP_3V3.TP, U1.P$A22 (VDD), U1.P$AD14 (VDD), U1.P$AD23 (VDD), U1.P$B1 (VDD), U1.P$W1 (VDD), U1.P$Y2 (VDDH)
ALERT: U1.P$J24 (P0.10/NFC2), U3.5 (!ALERT)
D+: D3.4 (I/O2_2), U1.P$AD6 (D+)
D-: D3.6 (I/O1_2), U1.P$AD4 (D-)
DEC1: C5.1, U1.P$C1 (DEC1)
DEC3: C11.1, U1.P$D23 (DEC3)
DEC4_6: C10.1, C15.1, C16.1, L3.2, U1.P$B5 (DEC4), U1.P$E24 (DEC6)
DN: D3.1 (I/O1_1), J4.A7 (DN1), J4.B7 (DN2)
DP: D3.3 (I/O2_1), J4.A6 (DP1), J4.B6 (DP2)
EPD_3V3: C1-EP-DR.1, EPD_C5.2, J1.15, J1.16, L5.2, Q1.3 (D)
EPD_BUSY: J1.9, U1.P$AD12 (P0.17)
EPD_CS: J1.12, U1.P$K2 (P0.05/AIN3)
EPD_DC: J1.11, U1.P$AD10 (P0.15)
EPD_RST: J1.10, U1.P$AC11 (P0.16)
GDR: J1.2, Q3.1 (G), R2_EP_DR.2
GND: C1.2, C1-EP-DR.2, C2.2, C3.2, C4.2, C5.2, C6.2, C7.2, C8.2, C9.2, C10.2, C11.2, C12.2, C13.2, C14.2, C15.2, C16.2, C17.1, C18.1, C19.2, C20.2, C21.2, C22.2, C23.2, C24.1, C25.2, C27.1, C29.1, C30.1, C31.1, C32.1, C33.2, C34.1, C37.1, C38.1, C39.2, C42.1, C43.2, D3.2 (GND), D4.1 (K), EPD_C1.1, EPD_C2.1, EPD_C5.1, EPD_C6.1, EPD_C7.1, EPD_C8.1, EPD_C9.1, EPD_C10.1, EPD_C11.1, EPD_C12.1, IC1.D2 (GND), IC2.B1 (IN/TRIG), IC2.B3 (GND), IC3.8 (GNDIO), IC3.9 (GND), IC9.B1 (VSEL), IC9.C1 (AGND), IC9.C2 (PGND_1), IC9.C3 (PGND_2), J1.8, J1.17, J1.MP1, J1.MP2, J2.3, J2.5, J4.A1_B12 (GND), J4.A12_B1 (GND), J4.SH1 (SHIELD), J4.SH2 (SHIELD), J4.SH3 (SHIELD), J4.SH4 (SHIELD), R1_TYPE_SEL.1, R1_USB.1, R2_EP_DR.1, R2_USB.2, R3.1, R9.1, SJ1.1, SW_DN.1, SW_ENT.1, SW_UP.1, TP_BAT_GND.TP, TP_GND.TP, U1.P$74 (VSS_PAD), U1.P$75 (VSS_PAD), U1.P$76 (VSS_PAD), U1.P$77 (VSS_PAD), U1.P$78 (VSS_PAD), U1.P$79 (VSS_PAD), U1.P$80 (VSS_PAD), U1.P$81 (VSS_PAD), U1.P$82 (VSS_PAD), U1.P$83 (VSS_PAD), U1.P$84 (VSS_PAD), U1.P$85 (VSS_PAD), U1.P$86 (VSS_PAD), U1.P$87 (VSS_PAD), U1.P$88 (VSS_PAD), U1.P$89 (VSS_PAD), U1.P$90 (VSS_PAD), U1.P$B7 (VSS), U1.P$F23 (VSS_PA), U3.1 (CTG), U3.4 (GND), U3.6 (QSTRT), U3.9 (EP), X1.2, X1.4
HAPTIC_EN: IC2.A1 (EN), U1.P$U1 (P0.12)
IMU_INT1: IC3.5 (INT1), U1.P$N1 (P0.08)
IMU_INT2: IC3.6 (INT2), U1.P$P2 (P1.08)
LX1: IC9.B2 (SW1_1), IC9.B3 (SW1_2), L7.1
LX2: IC9.D2 (SW2_1), IC9.D3 (SW2_2), L7.2
MOSI: J1.14, U1.P$B13 (P0.03/AIN1)
unnamed: L2.1, U1.P$B3 (DCC)
unnamed: L2.2, L3.1
unnamed: C13.1, U1.P$A18 (DEC2)
unnamed: C1.1, U1.P$B24 (XC1), X1.1
unnamed: C2.1, U1.P$A23 (XC2), X1.3
unnamed: C3.1, L1.1, U1.P$H23 (ANT)
unnamed: ANT1.1 (FEED), C4.1, C22.1, L1.2
unnamed: C9.1, U1.P$N24 (DEC5)
unnamed: C20.1, U1.P$AC5 (DEC3V3)
unnamed: IC9.D1 (SCL), R4.2
unnamed: IC9.E1 (SDA), R2.2
unnamed: IC1.D1 (TS/MR), R9.2
unnamed: C25.1, IC9.E2 (VOUT_1)
unnamed: IC3.1 (SDO), R3.2
unnamed: C2-EP-DR.2, D5.2 (A), L5.1, Q3.3 (D)
unnamed: C2-EP-DR.1, D2.1 (K), D4.2 (A)
unnamed: R1_EP_DR.1, R1_TYPE_SEL.2, SJ1.2
unnamed: EPD_C2.2, J1.4
unnamed: EPD_C1.2, J1.5
unnamed: EPD_C6.2, J1.18
unnamed: EPD_C7.2, J1.19
unnamed: EPD_C8.2, J1.20
unnamed: J4.A5 (CC1), R1_USB.2
unnamed: EPD_C10.2, J1.22
unnamed: J4.B5 (CC2), R2_USB.1
unnamed: EPD_C12.2, J1.24
unnamed: C32.2, IC2.A2 (REG)
OUT+: IC2.A3 (OUT+), TP_OP.TP
OUT-: IC2.C3 (OUT-), TP_ON.TP
P0.00/XL1: C17.2, U1.P$D2 (P0.00/XL1), X2.2
P0.01/XL2: C18.2, U1.P$F2 (P0.01/XL2), X2.1
P0.04: U1.P$J1 (P0.04/AIN2)
P0.09: U1.P$L24 (P0.09/NFC1)
P0.13: C30.2, R5.1, SW_UP.2, U1.P$AD8 (P0.13)
P0.14: C31.2, R8.1, SW_ENT.2, U1.P$AC9 (P0.14)
P0.19: U1.P$AC15 (P0.19)
P0.20: U1.P$AD16 (P0.20)
P0.21: U1.P$AC17 (P0.21)
P0.22: U1.P$AD18 (P0.22)
P0.23: U1.P$AC19 (P0.23)
P0.24: U1.P$AD20 (P0.24)
P0.25: U1.P$AC21 (P0.25)
P0.26: U1.P$G1 (P0.26)
P0.27: U1.P$H2 (P0.27)
P0.28: U1.P$B11 (P0.28/AIN4)
P0.29: U1.P$A10 (P0.29/AIN5)
P0.30: U1.P$B9 (P0.30/AIN6)
P0.31: U1.P$A8 (P0.31/AIN7)
P1.01: Q1.1 (G), R_PWR_EPD.1, U1.P$Y23 (P1.01)
P1.02: C29.2, R7.1, SW_DN.2, U1.P$W24 (P1.02)
P1.03: U1.P$V23 (P1.03)
P1.04: U1.P$U24 (P1.04)
P1.05: U1.P$T23 (P1.05)
P1.06: U1.P$R24 (P1.06)
P1.07: U1.P$P23 (P1.07)
P1.09: U1.P$R1 (P1.09)
P1.10: U1.P$A20 (P1.10)
P1.11: U1.P$B19 (P1.11)
P1.12: U1.P$B17 (P1.12)
P1.13: U1.P$A16 (P1.13)
P1.14: U1.P$B15 (P1.14)
P1.15: U1.P$A14 (P1.15)
PMIC_INT: IC1.A1 (!INT), U1.P$T2 (P0.11)
PREVGH: D2.2 (A), D5.1 (K), EPD_C9.2, J1.21
PREVGL: EPD_C11.2, J1.23
RESE: J1.3, Q3.2 (S), R1_EP_DR.2
RESET: J2.6, TP_RESET.TP, U1.P$AC13 (P0.18/RESET)
SCK: J1.13, U1.P$A12 (P0.02/AIN0)
SCL: IC1.B1 (SCL), IC2.C1 (SCL), IC3.12 (SCX), R4.1, R17.2, TP_SCL.TP, U1.P$M2 (P0.07), U3.7 (SCL)
SDA: IC2.B2 (SDA), U3.8 (SDA)
SDL: IC1.C1 (SDA), IC3.2 (SDX), R2.1, R18.2, TP_SDA.TP, U1.P$L1 (P0.06)
SWDCLK: J2.4, TP_SWDCLK.TP, U1.P$AA24 (SWDCLK)
SWDIO: J2.2, TP_SWDIO.TP, U1.P$AC24 (SWDIO)
SWO: TP_SWO.TP, U1.P$AD22 (P1.00)
VBAT: C27.2, C37.2, IC1.C2 (BAT), TP_VBAT.TP, U3.2 (CELL), U3.3 (VDD)
VBUS: C21.1, C38.2, C42.2, C43.1, D3.5 (VBUS), IC1.A2 (IN), J4.A4_B9 (VBUS), J4.A9_B4 (VBUS), U1.P$AD2 (VBUS)
VREG: C23.1, C24.2, C39.1, IC1.B2 (SYS), IC9.A1 (EN), IC9.A2 (VIN_1), IC9.A3 (VIN_2), TP_VREG.TP

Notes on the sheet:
SWD
LiPo Charger
DC/DC
IMU
E-Paper Drive Circuit
E-Paper Display Connector
Fuel Gauge
USB C Connector & ESD Protection

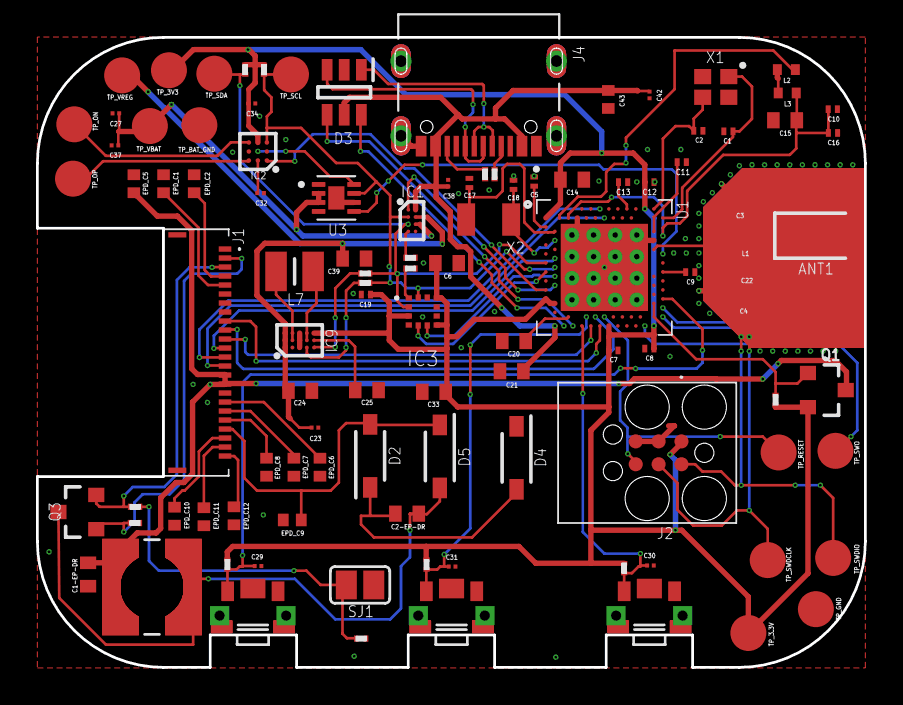
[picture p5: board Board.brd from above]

Board: 2 copper layers, 46.0 x 35.0 mm, 105 parts (0 on the bottom side), 72 nets.

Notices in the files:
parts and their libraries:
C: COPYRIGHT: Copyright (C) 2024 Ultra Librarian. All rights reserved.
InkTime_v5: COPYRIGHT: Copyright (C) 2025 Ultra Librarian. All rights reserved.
